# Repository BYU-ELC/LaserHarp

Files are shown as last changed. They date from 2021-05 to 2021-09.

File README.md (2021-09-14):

# LaserHarp
Contains code and project files for the Laser Harp project

The Laser harp project accepts inputs from the laser sensors/beams. When a laser beam is interrupted, the consequent signal will be converted into a musical/audio output corresponding with the 'string' played. As such, this functions generally as a classical harp, simply implementing the lasers to operate as harp strings.

Currently the project is controlled by a teensy with an audio shield. The 5 volt power source is stepped down to 3.3 volts to power 8 always on lasers which are pointed at photodiodes. The photodiodes each have a simple BJT circuit to amplify their output which is detected by the teensy. The audio shield on the teensy generates a tone every time a laser beam is interrupted.

The original board schematic is handwritten in LaserHarpSchematic.pdf, but the new schematics and layouts are in the Laser Harp PCB.sch and Laser Harp PCB.brd files respectively. You should use these for future development or repair.

 --

FUTURE DEVELOPMENT:

Currently the Laser Harp is using a PCB we milled out here in the shop which is nice, but it might be nice to order a professional one. Also, it is Revision 2, meaning I had to manually change the connection from pin 7 to pin 8 (See schematic commit notes).

If the Photo Diode boards are ever replaced, you should add an additional pad to the board to make it easier to connect the power supply since it runs from one board to the next.

It might be nicer to have the buttons attached to the Laser Harp PCB instead of on a separate board, or at least mounted on the base of the Laser Harp more professionally.

The fog currently works, but it could be improved by replacing the fans on the reservoir with stronger fans and possibly redoing the tubing to get better fog distribution.

If someone can find a library of actual harp audio files (instead of piano), that would be awesome. Just make sure to format the files as described the in the Laser Harp Hardware Documentation.

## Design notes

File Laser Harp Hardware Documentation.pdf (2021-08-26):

BYU Laser Harp Hardware Documentation

The laser harp runs on a Teensy 3.1 with the addition of the Teensy Audio Adapter Board Rev B. Both are somewhat outdated, so it may be difficult to find documentation for them specifically, but they are almost equivalent to the Teensy 3.2 and the Audio Adapter Board Rev C. Documentation can be found: https://www.pjrc.com/teensy/teensy31.html
https://www.pjrc.com/store/teensy3_audio.html
For reference, the following are the pinouts:

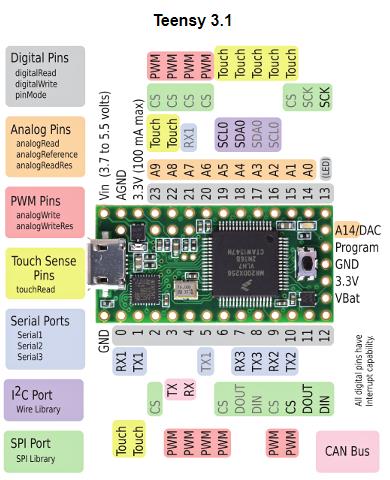
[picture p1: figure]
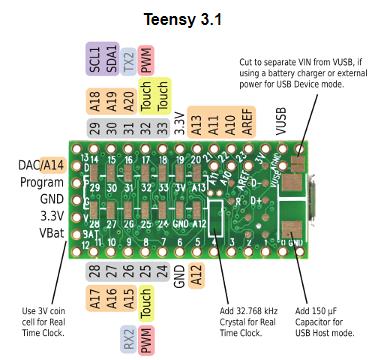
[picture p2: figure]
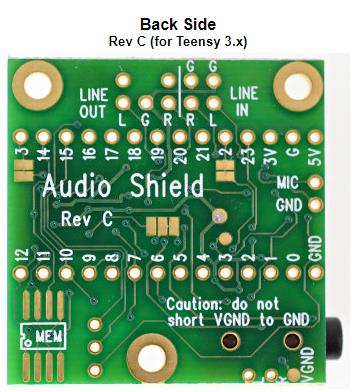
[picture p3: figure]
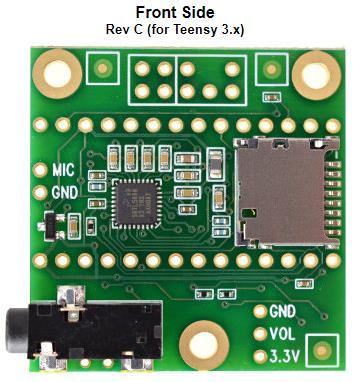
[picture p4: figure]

Note that the Audio Shield Rev B has the same pinout as the Audio Shield Rev C.

The Teensy 3.1 plays wav files stored on a micro-SD card that is accessed via the Audio Shield. Note that for the audio files to be playable by the Teensy, they must not only be wav files, but they must also be sampled at 44.1 kHz. Other sample rates won’t work. Wav files with other sample rates can be easily converted online at:
https://onlineaudioconverter.com/

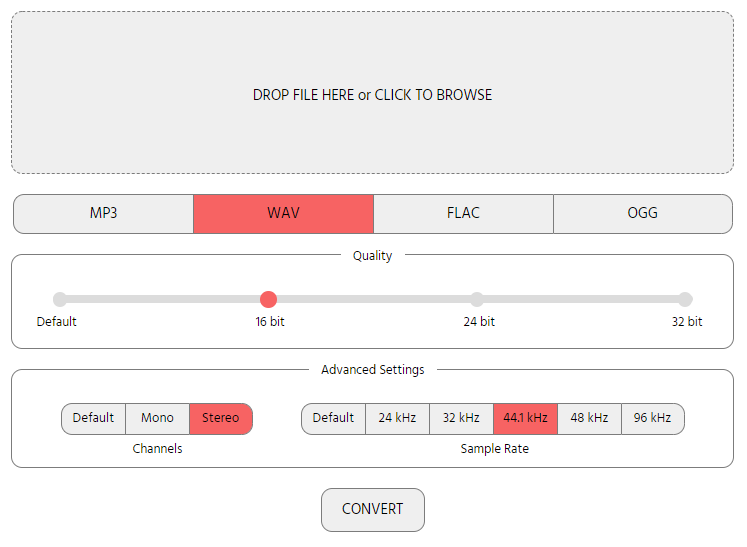
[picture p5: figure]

Though it is tedious because you have to do one file at a time. After converting, simply save the files to the micro-SD card by plugging it in to your computer and moving the files. Once your files are moved over, then you can insert it into the port on the Audio Shield and so long as the Teensy is connected, it will be able to read the files.

Lasers
There are 8 lasers on the harp, plus we ordered 2 extra as well. They are green dot laser modules that we added longer wires, extra hot glue, heat shrink, and Molex headers to. Replacements can be ordered at:
https://www.amazon.com/Lights88-Green-Modules-GM532-50-Solder/dp/B07PT4X966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 (https://www.amazon.com/Lights88-Green-Modules-GM532-50-Solder/dp/B07PT4X966)
Operating voltage: 3.2 V
Operating current: ~100-200 mA
Output power (light): probably about 5-10 mW

Sensors
Photodiode connected to 5 V. The photodiode controls the base of the BJT, now found on the PCB. The BJT emitter connects to an input pin on the teensy.

Voltage Regulators
Output voltage: 3.3 V
Output current: 800 mA (each)
Pinout: left pin ground, center pin output, right pin input

Circuit Board
A DC barrel jack provides 5V to the teensy, the BJTs, the photodiodes, and the voltage regulators. The voltage regulators provide 3.3V to the lasers. When a laser beam is blocked, the signal on the input pins goes low and signals the teensy to play a note. See schematic for more detail.

Input Pins
The sensors attach to pins 0, 1, 2, 3, 4, 5, 6, and 8. Pin 7 is skipped because this is the pin which the Teensy uses to read from the micro-SD card. The buttons attach to pins 20 and 21.

Frame
The frame is solid aluminum and was previously cut to the shape it is. The holes for the lasers are cut at 60 degrees above horizontal. We added the new mountings which include three mounting screws each, allowing for better aiming of the lasers with a firm, but non-permanent hold. These were attached to the aluminum frame using epoxy. The base was cut in the ELC and then attached to the frame using screws.

Fog
The transducers in the reservoir vibrate in such a way that they vaporize water when submerged. Using this technique, we can create a fog that allows us to see the laser beams more easily. A reservoir was attached to the back of the base and the transducers are placed inside the reservoir. Two small fans pressurize the reservoir and push the fog vapor up the tubes, misting the area where the laser beams are.

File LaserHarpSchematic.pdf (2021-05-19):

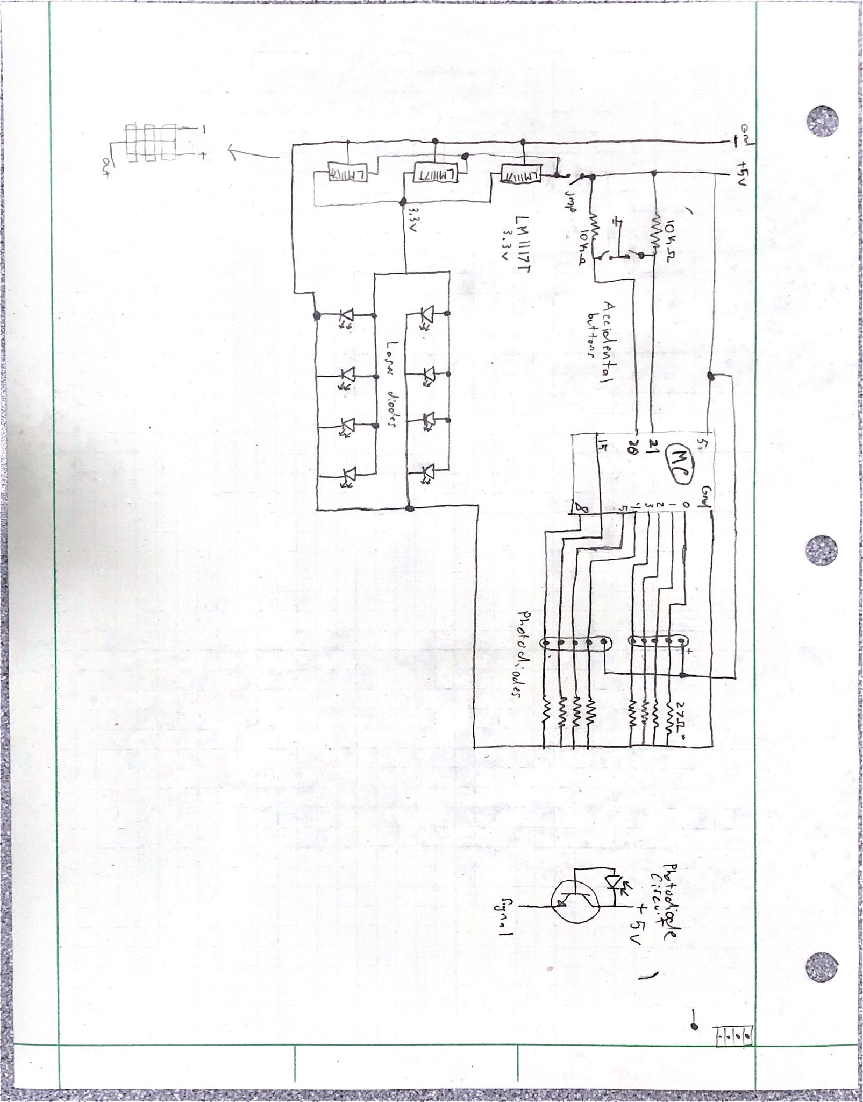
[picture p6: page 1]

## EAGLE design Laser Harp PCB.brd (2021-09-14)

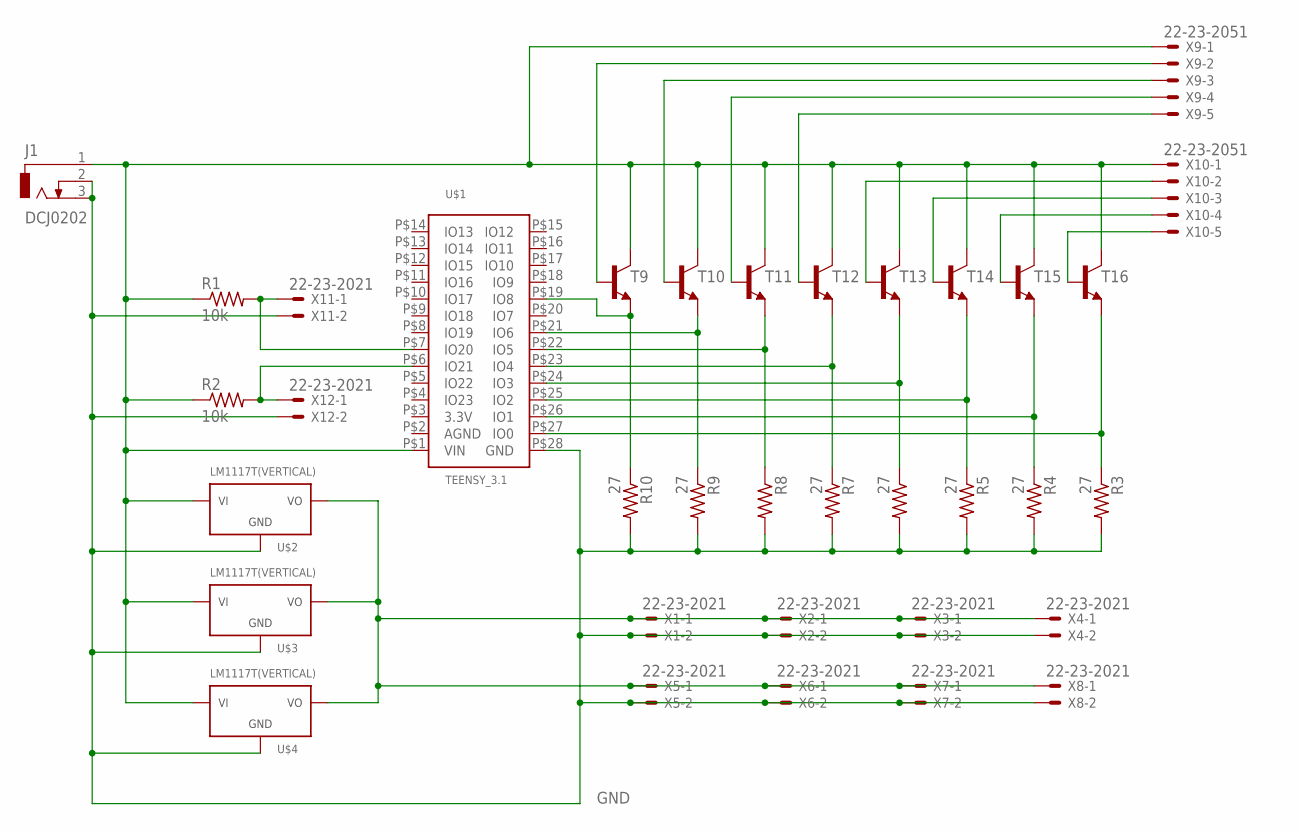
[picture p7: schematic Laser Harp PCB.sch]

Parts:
J1: DCJ0202
R1, R2: 10k; 0207/7
R3, R4, R5, R6, R7, R8, R9, R10: 27; 0207/7
T9, T10, T11, T12, T13, T14, T15, T16: 2N3904-NPN-TO92-EBC; TO92-EBC
U$1: TEENSY_3.1
U$2, U$3, U$4: LM1117T(VERTICAL); 317TS
X1, X2, X3, X4, X5, X6, X7, X8, X11, X12: 22-23-2021
X9, X10: 22-23-2051

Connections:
GND: J1.2, J1.3, R3.2, R4.2, R5.2, R6.2, R7.2, R8.2, R9.2, R10.2, U$1.P$28 (GND), U$2.1 (GND), U$3.1 (GND), U$4.1 (GND), X1.2, X2.2, X3.2, X4.2, X5.2, X6.2, X7.2, X8.2, X11.2, X12.2
unnamed: U$2.2 (VOUT), U$3.2 (VOUT), U$4.2 (VOUT), X1.1, X2.1, X3.1, X4.1, X5.1, X6.1, X7.1, X8.1
unnamed: J1.1, R1.1, R2.1, T9.C, T10.C, T11.C, T12.C, T13.C, T14.C, T15.C, T16.C, U$1.P$1 (VIN), U$2.3 (VIN), U$3.3 (VIN), U$4.3 (VIN), X9.1, X10.1
unnamed: R3.1, T16.E, U$1.P$27 (IO0)
unnamed: R4.1, T15.E, U$1.P$26 (IO1)
unnamed: R5.1, T14.E, U$1.P$25 (IO2)
unnamed: R6.1, T13.E, U$1.P$24 (IO3)
unnamed: R7.1, T12.E, U$1.P$23 (IO4)
unnamed: R8.1, T11.E, U$1.P$22 (IO5)
unnamed: R9.1, T10.E, U$1.P$21 (IO6)
unnamed: R2.2, U$1.P$6 (IO21), X12.1
unnamed: R1.2, U$1.P$7 (IO20), X11.1
unnamed: R10.1, T9.E, U$1.P$19 (IO8)
unnamed: T9.B, X9.2
unnamed: T10.B, X9.3
unnamed: T11.B, X9.4
unnamed: T12.B, X9.5
unnamed: T13.B, X10.2
unnamed: T14.B, X10.3
unnamed: T15.B, X10.4
unnamed: T16.B, X10.5

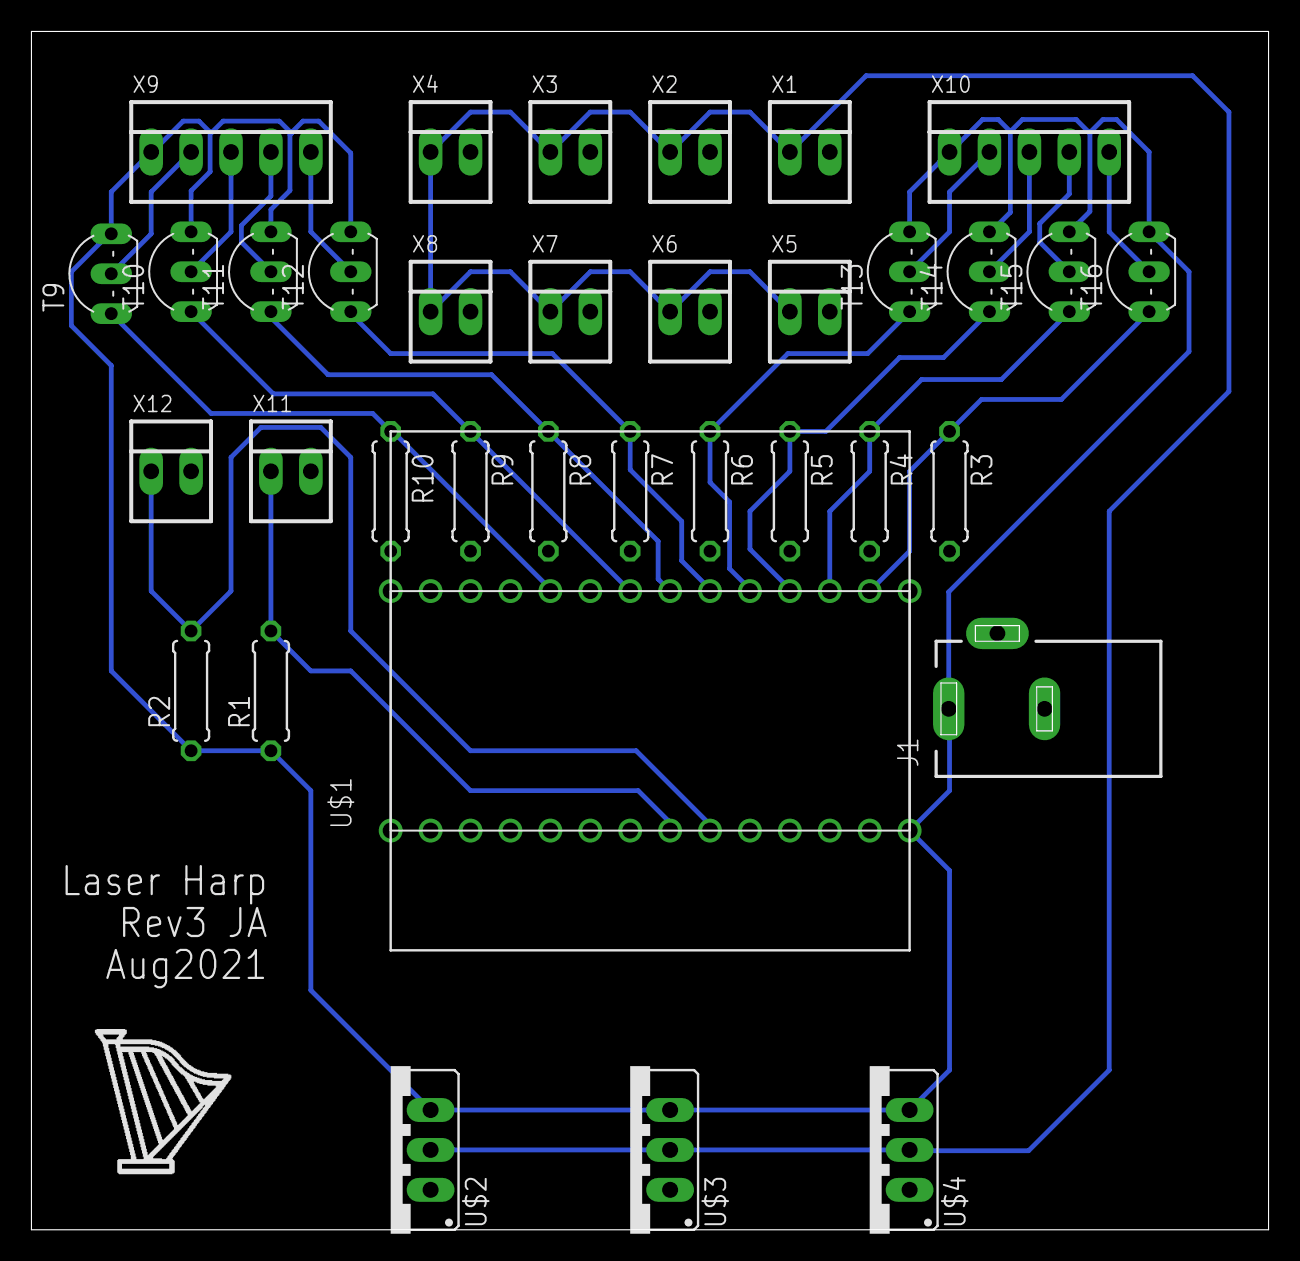
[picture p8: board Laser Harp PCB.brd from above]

Board: 2 copper layers, 78.7 x 76.3 mm, 35 parts (0 on the bottom side), 21 nets.

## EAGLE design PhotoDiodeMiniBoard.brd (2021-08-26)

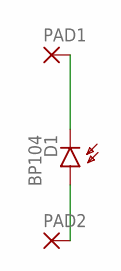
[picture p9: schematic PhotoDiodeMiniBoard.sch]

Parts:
D1: BP104
PAD1, PAD2: 2,15/1,0

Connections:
unnamed: D1.K (C), PAD1.1
unnamed: D1.A, PAD2.1

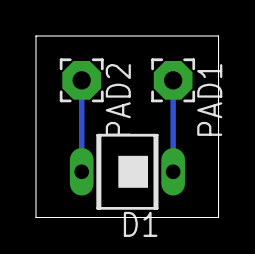
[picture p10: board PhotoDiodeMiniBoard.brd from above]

Board: 2 copper layers, 10.1 x 10.1 mm, 3 parts (0 on the bottom side), 2 nets.

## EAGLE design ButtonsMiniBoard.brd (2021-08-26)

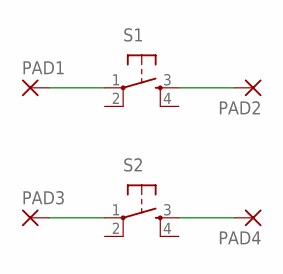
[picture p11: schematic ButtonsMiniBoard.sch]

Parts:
PAD1, PAD2, PAD3, PAD4: 2,15/1,0
S1, S2: TAC_SWITCHPTH; TACTILE-PTH

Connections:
unnamed: PAD1.1, S1.1
unnamed: PAD2.1, S1.3
unnamed: PAD3.1, S2.1
unnamed: PAD4.1, S2.3

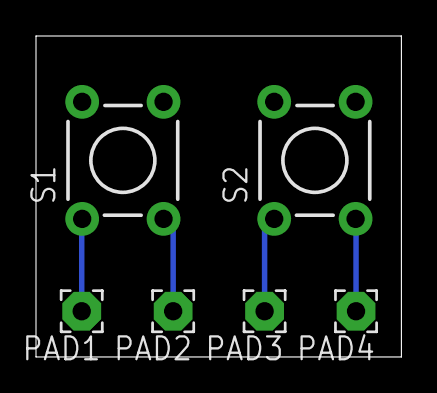
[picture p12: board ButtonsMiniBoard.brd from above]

Board: 2 copper layers, 20.3 x 17.8 mm, 6 parts (0 on the bottom side), 4 nets.

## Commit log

2021-05-19 Add hand written schematic
2021-05-26 Create Teensy Audio Test Code
    This is test code used to verify the functionality of the Teensy 3.1, the Audio Adapter Board Rev B, and the SD card. All are working, and the program successfully reads and plays the wav files on th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
2021-08-24 Update Basic Functionality Code
    Updated pin numbers based on the new PCB layout
2021-08-26 Schematics and Board Layouts
    Schematics and Board Layouts for the main PCB, the buttons board, and the photodiode board. These are for the working revision used at NSO. Further revision may improve the design.
    [ButtonsMiniBoard.brd, ButtonsMiniBoard.sch, Laser Harp PCB.brd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]
2021-08-27 Create Improved Code
    This code contains improvements like allowing the user to play multiple notes simultaneously (up to 3, the teensy doesn't handle more than 3 well), shifting the range of the notes, switching between a major and minor scale, and preventing the lasers from playing over and over if you keep one blocked.
    One button shifts down a half step, the other shifts up a half step. The high and low notes loop around when you reach the extremes. Pressing both buttons together changes between a major and minor scale.
2021-09-14 Updated pin connection
    The BJTs used to connect to pins 0 through 7 of the Teensy, but the Audio Shield uses pin 7 to transmit information from the micro sd card to the Teensy. I changed the connection from pin 7 to pin 8.
    [Laser Harp PCB.sch]
2021-09-14 Update pin connections
    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
    [Laser Harp PCB.brd]
2021-09-14 Rename Teensy Audio Test Code to Code - Teensy Audio Test
